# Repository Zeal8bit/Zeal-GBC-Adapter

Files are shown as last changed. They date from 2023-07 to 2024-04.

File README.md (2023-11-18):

## Gameboy (Color) cartridge adapter for Zeal 8-bit Computer

<center>
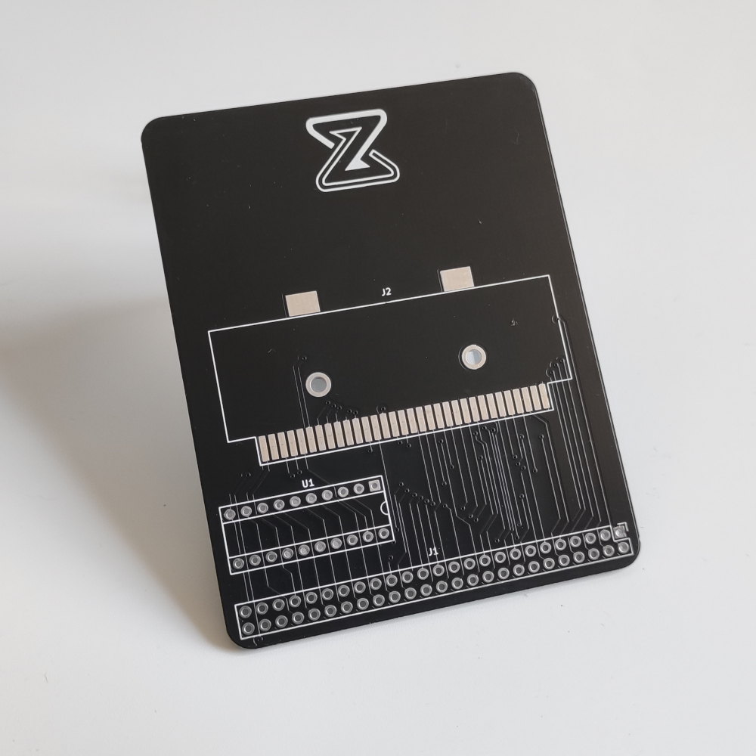
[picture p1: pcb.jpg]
PCB final result
    
</center>

### This repository is part of [this Youtube video](https://www.youtube.com/watch?v=MxnD7FFjDEM), check it for more information and explanation about this project.

The goal of this project is to create an adapter for connecting any Gameboy or Gameboy Color cartridge to Zeal 8-bit Computer. This will offer the possibility to backup the ROM or RAM (saved data), restore the saved data or even modify the saved data in place.

This repository includes:

* An example program, written in C, to communicate with the adapter. It will read RAM banks from the cartridge and send them through UART. This has been tested with MBC1 and MBC5 cartridges.
* A Python script to run on a host that will receive the data from UART and save them inside a file
* The source code to flash to the PLD (GAL16V8)
* A Kicad (v6) project for the schematics and PCB board

**DISCLAIMER: To prevent any data loss, NEVER plug or unplug the cartridges from the adapter when it is connected to a computer/board that is powered on! I am not responsible for any potential damage caused to the Gameboy cartridge when using the adapter. Use it at your own risk.**

### Requirements

To compile this example you will need:

* python3
  * pyserial package (`pip3 install pyserial`)
* bash
* git (to clone this repo)
* make
* Zeal 8-bit OS source code. Only the `kernel_headers` directory is required, check this repository.
z88dk v2.2 (or later). Only its assembler, z80asm, is strictly required. The latest version of z80asm must be used as earlier versions don't have support for `MACRO`.
To install z88dk, please check out their GitHub project.

### Build

To build the program, define the path to Zeal 8-bit OS, this will let us find the header files used to assemble the example:

```
export ZOS_PATH=/your/path/to/Zeal8bitOS
```

Then simply use the command:

```
cd software
make
```

After compiling, the folder `bin/` in `software/` should contain the binary `dump.bin`. This file can be then loaded to Zeal 8-bit OS through UART thanks to the `load` command.

The binary can also be embedded within the romdisk that will contain both the OS and a read-only file system. For example:

```
cd $ZOS_PATH
export EXTRA_ROMDISK_FILES="/path/to/this/repo/software/bin/dump.bin"
make
```

More info about compiling [Zeal 8-bit OS here](https://github.com/Zeal8bit/Zeal-8-bit-OS#getting-started).

The resulting ROM image can then be provided to an emulator or directly flashed to the computer's ROM that will use it.

### Usage

* On the Zeal 8-bit Computer, execute the dump program from the command line:

    ```
    A:/> ./dump.bin
    ```
    The program should detect the cartridge name, the RAM banks count and their size. The output should look like:
    ```
    POKEMON BLUE
    Cartridge type: 0x3
    Cartridge RAM size: 32 KB
    Ready to send, start the dump script on the host computer
    ```

* **Close the serial monitor on the host computer!** Else, the python script below will not be able to receive characters from the UART.

* On the host, execute the python script, you can use `-h` to have more info about the parameters. For example, to save the file as `PKM.sav` from UART node `/dev/ttyUSB0` with a baudrate of 57600, the following command can be used:

    ```
    python3 dump.py -o PKM.sav -d /dev/ttyUSB0 -b57600 -v
    ```

    The output should look like this:

    ```
    Connecting to /dev/ttyUSB0 with baudrate 57600
    Dumping 4 banks of 8192 bytes, 32768 bytes in total...
    PKM.sav successfully dumped
    ```

## Troubleshooting

Upon execution of the binary on the Zeal 8-bit computer, you may encounter the `Get attr error` issue. This shows that the serial driver in the Zeal 8-bit OS kernel doesn't support setting attributes (raw) via `ioctl`. In that case, you should update your installation of the Zeal 8-bit OS to get the latest version of the serial driver.

## License

Distributed under the Creative Commons Zero v1.0 Universal License. See LICENSE file for more information.

You are free to use it for personal and commercial use, the boilerplate present in each file must not be removed.

The `zeal8bit.com` silkscreen present on the PCB shall be kept.

## Contact

For any suggestion or request, you can contact me at contact [at] zeal8bit [dot] com or on the Discord server https://discord.gg/UzEjwRvBBb

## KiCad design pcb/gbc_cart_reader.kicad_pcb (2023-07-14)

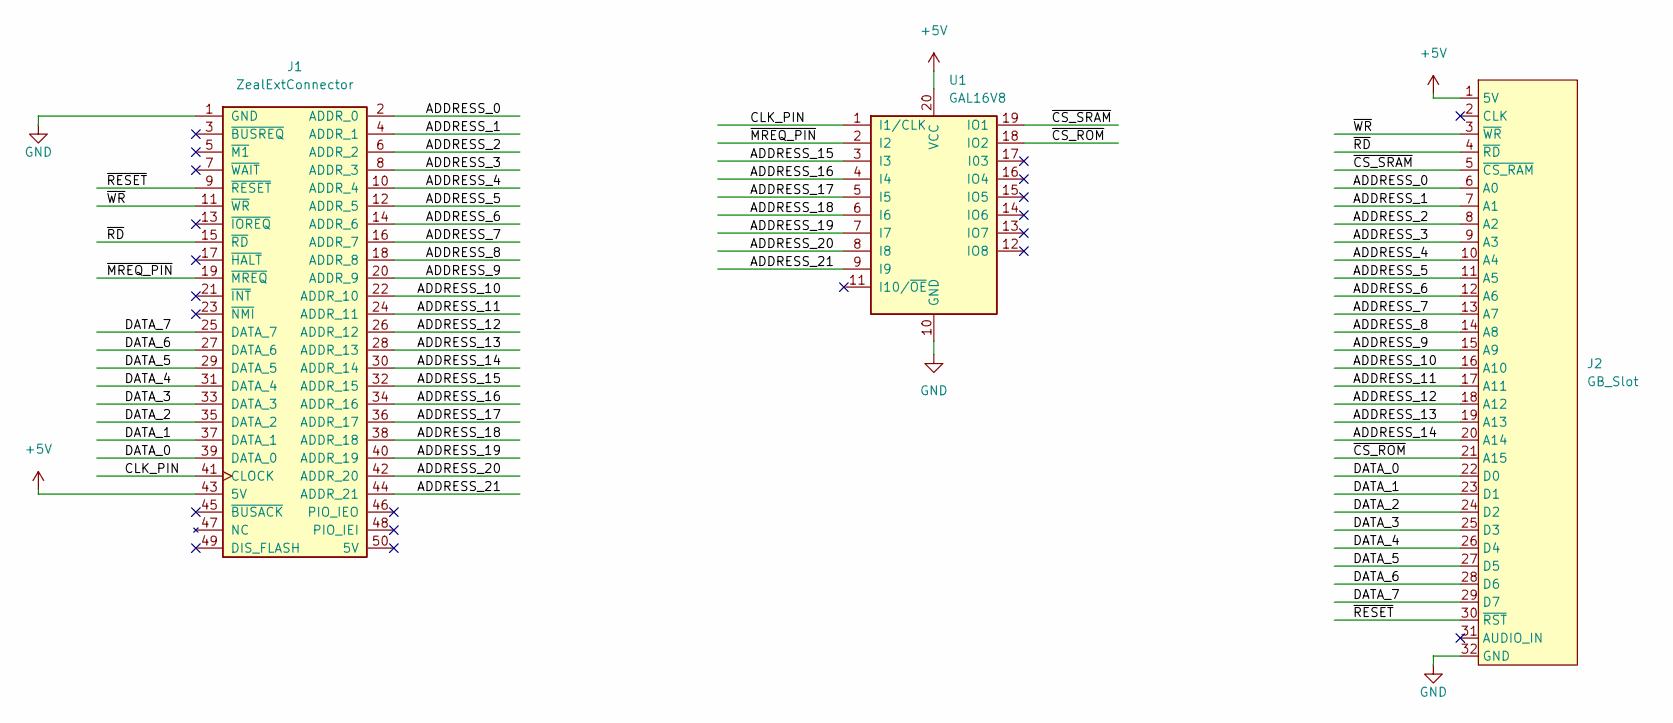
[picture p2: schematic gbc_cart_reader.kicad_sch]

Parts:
J1: ZealExtConnector; PinHeader_2x25_P2.54mm_Vertical
J2: GB_Slot; GB Slot
U1: GAL16V8; DIP-20_W7.62mm_Socket

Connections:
+5V: J1.43 (5V), J2.1 (5V), U1.20 (VCC)
/ADDRESS_0: J1.2 (ADDR_0), J2.6 (A0)
/ADDRESS_1: J1.4 (ADDR_1), J2.7 (A1)
/ADDRESS_2: J1.6 (ADDR_2), J2.8 (A2)
/ADDRESS_3: J1.8 (ADDR_3), J2.9 (A3)
/ADDRESS_4: J1.10 (ADDR_4), J2.10 (A4)
/ADDRESS_5: J1.12 (ADDR_5), J2.11 (A5)
/ADDRESS_6: J1.14 (ADDR_6), J2.12 (A6)
/ADDRESS_7: J1.16 (ADDR_7), J2.13 (A7)
/ADDRESS_8: J1.18 (ADDR_8), J2.14 (A8)
/ADDRESS_9: J1.20 (ADDR_9), J2.15 (A9)
/ADDRESS_10: J1.22 (ADDR_10), J2.16 (A10)
/ADDRESS_11: J1.24 (ADDR_11), J2.17 (A11)
/ADDRESS_12: J1.26 (ADDR_12), J2.18 (A12)
/ADDRESS_13: J1.28 (ADDR_13), J2.19 (A13)
/ADDRESS_14: J1.30 (ADDR_14), J2.20 (A14)
/ADDRESS_15: J1.32 (ADDR_15), U1.3 (I3)
/ADDRESS_16: J1.34 (ADDR_16), U1.4 (I4)
/ADDRESS_17: J1.36 (ADDR_17), U1.5 (I5)
/ADDRESS_18: J1.38 (ADDR_18), U1.6 (I6)
/ADDRESS_19: J1.40 (ADDR_19), U1.7 (I7)
/ADDRESS_20: J1.42 (ADDR_20), U1.8 (I8)
/ADDRESS_21: J1.44 (ADDR_21), U1.9 (I9)
/CLK_PIN: J1.41 (CLOCK), U1.1 (I1/CLK)
/DATA_0: J1.39 (DATA_0), J2.22 (D0)
/DATA_1: J1.37 (DATA_1), J2.23 (D1)
/DATA_2: J1.35 (DATA_2), J2.24 (D2)
/DATA_3: J1.33 (DATA_3), J2.25 (D3)
/DATA_4: J1.31 (DATA_4), J2.26 (D4)
/DATA_5: J1.29 (DATA_5), J2.27 (D5)
/DATA_6: J1.27 (DATA_6), J2.28 (D6)
/DATA_7: J1.25 (DATA_7), J2.29 (D7)
/~CS_ROM: J2.21 (A15), U1.18 (IO2)
/~CS_SRAM: J2.5 (~CS_RAM), U1.19 (IO1)
/~MREQ_PIN: J1.19 (~MREQ), U1.2 (I2)
/~RD: J1.15 (~RD), J2.4 (~RD)
/~RESET: J1.9 (~RESET), J2.30 (~RST)
/~WR: J1.11 (~WR), J2.3 (~WR)
GND: J1.1 (GND), J2.32 (GND), U1.10 (GND)

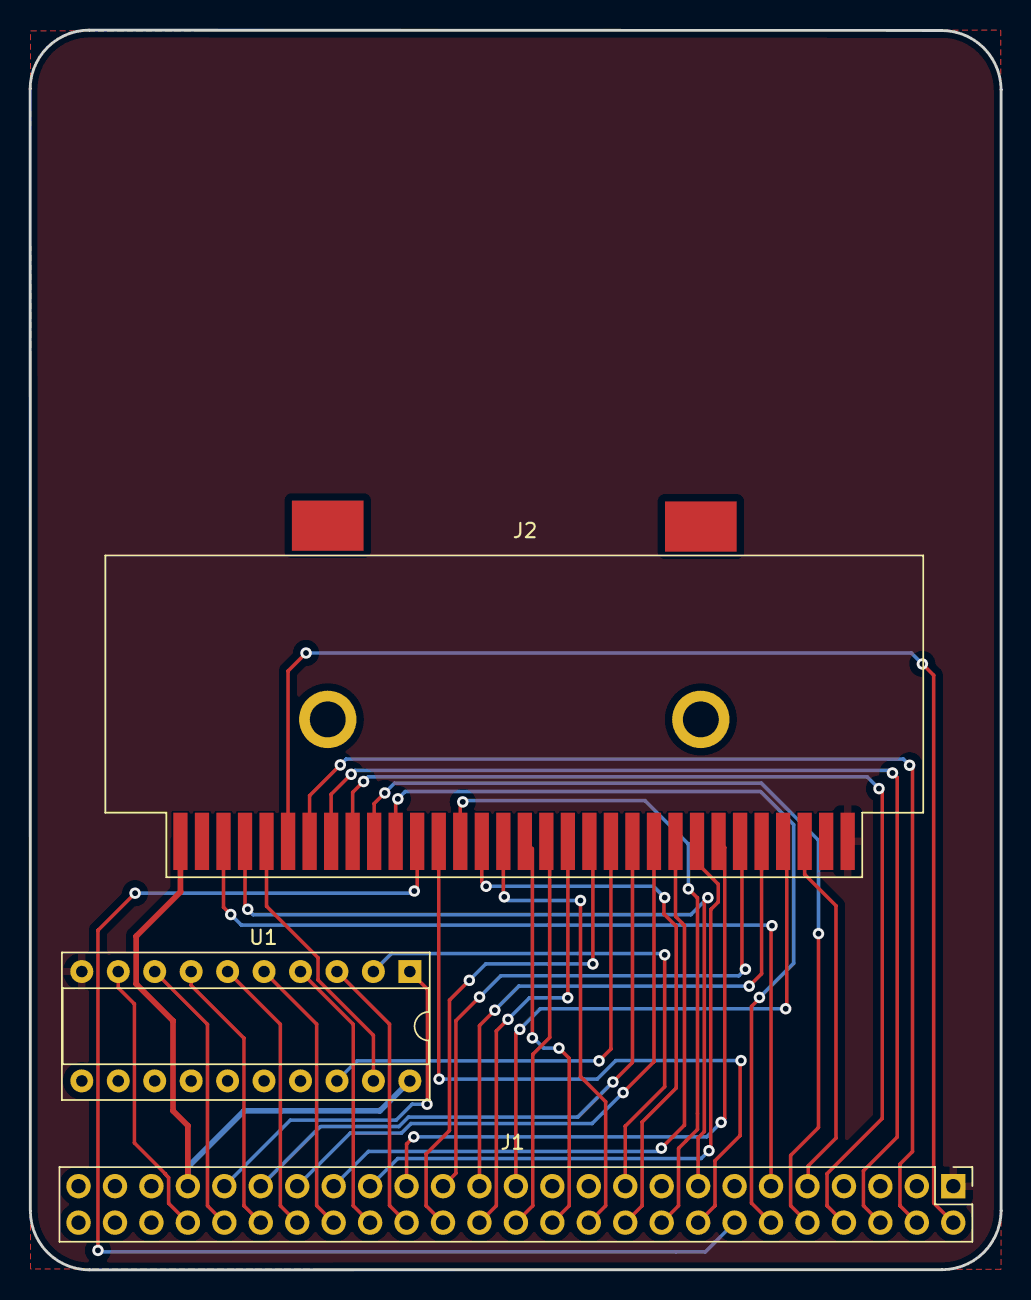
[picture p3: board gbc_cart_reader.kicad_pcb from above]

Board: 2 copper layers, 67.7 x 86.4 mm, 3 parts (0 on the bottom side), 39 nets.

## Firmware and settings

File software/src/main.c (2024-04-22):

/* SPDX-FileCopyrightText: 2023 Zeal 8-bit Computer <contact@zeal8bit.com>
 *
 * SPDX-License-Identifier: CC0-1.0
 */

#include <stdio.h>
#include <stdint.h>
#include <stdlib.h>
#include "zos_errors.h"
#include "zos_vfs.h"
#include "zos_sys.h"
#include "zos_serial.h"

/* If the standard output is the same serial driver as the one used to backup the cartridge,
 * we shall not output anything during the dump. After backing up, wait for a character before exiting. */
#define STDOUT_IS_SERIAL    1

/* Define different cartridges type */
#define MBC1_RAM_BATT       0x3
#define MBC2_RAM_BATT       0x6
#define ROM_RAM_BATT        0x10
#define MBC3_RAM_BATT       0x13
#define MBC5_RAM_BATT       0x1b
#define MBC5_RUMB_RAM_BATT  0x1e

/* Gameboy cartridge will be mapped at physical address 0x3f0000  */
#define GB_PHYS_ADDR            (0x3f0000)

/**
 * The first page is the kernel, we can't touch it, the second page is the current program,
 * the third page is available and the forth page is the stack for this current program.
 * Use the third page to map the GB cartridge data
 */
#define GB_CART_VIRT_ADDR       (0x8000)

/**
 * Each SRAM bank in the cartridge is 8KB big
 */
#define GB_SRAM_BANK_SIZE       (8*1024)

/**
 * Pointer to the cartridge virtual address
 */
uint8_t* cart_virt = (uint8_t*) GB_CART_VIRT_ADDR;

/**
 * Opened dev for the UART, needs to be closed before exiting!
 */
zos_dev_t uart_dev = 0;

/**
 * Attributes of the opened UART
 */
uint16_t uart_attr = 0;

/**
 * @brief Helper function to map cartridge given address into virtual page 3
 *
 * @param cart_addr Relative address of the cartridge to map, MUST BE A MULTIPLE OF 16KB!
 */
static void map_cart_phys(uint16_t cart_addr)
{
    zos_err_t err = map((void*) GB_CART_VIRT_ADDR, GB_PHYS_ADDR + cart_addr);
    if (err != ERR_SUCCESS) {
        printf("Error cartridge map\n");
        if (uart_dev) {
            close(uart_dev);
        }
        exit(0);
    }
}

/**
 * @brief Map the given cartridge SRAM bank into virtual page 3
 */
static void map_cart_sram(uint8_t bank)
{
    /* To switch the bank, write to cartridge address 0x4000 */
    map_cart_phys(0x4000);
    /* Only keep the lower 4 bits */
    cart_virt[0] = bank & 0xF;
    /* SRAM bank was mapped in the cartridge itself! Map the SRAM into the virtual page */
    map_cart_phys(0x8000);
}


/**
 * @brief Size of the cartridge RAM size, in KB
 *
 * @param size_value Size byte located in the cartridge ROM, at offset 0x149
 */
uint8_t cartridge_RAM_size(uint8_t size_value)
{
    uint8_t size = 0;
    switch (size_value) {
        case 2:
            size = 8;
            break;
        case 3:
            size = 32;
            break;
        case 4:
            size = 128;
            break;
        case 5:
            size = 64;
            break;
        default:
            size = 0;
            break;
    }
    return size;
}

static void wait_for_host(uint8_t bank_num, uint16_t bank_size)
{
    zos_err_t err;
    uint16_t size = 0;
    char msg[4] = { 0 };

    printf("Ready to send, start the dump script on the host computer\n");
    while (1) {
        /* Wait for a message from the host */
        size = 1;
        err = read(uart_dev, msg, &size);

        /* Make sure it is '!' */
        if (err != ERR_SUCCESS || msg[0] != '!') {
            printf("Invalid message from the host, please retry\n");
            continue;
        }

        /* Send the number of banks and the bank size */
        msg[0] = '=';
        msg[1] = bank_num;
        msg[2] = bank_size & 0xff;
        msg[3] = bank_size >> 8;
        size = 4;
        write(uart_dev, msg, &size);
        break;
    }
}

int main (void)
{
    zos_err_t err;

    /* Open the serial driver to send the data to */
    uart_dev = open("#SER0", O_WRONLY);
    if (uart_dev < 0) {
        printf("Error opening serial driver\n");
        exit(0);
    }

    /* Start by mapping the fixed part of the ROM. It contains info about the cartridge itself.
     * (size, MBC, ram size, etc...) */
    map_cart_phys(0);

    /* Offset 0x134 of the cartridge should contain the name of the game, only print 15 characters */
    const char* name = cart_virt + 0x134;
    uint16_t size = 15;
    write(DEV_STDOUT, name, &size);

    /* Determine the size and number of the RAM banks thanks to the cartridge type, located at offset
     * 0x147 of the ROM. */
    uint8_t bank_num = 0;
    uint16_t bank_size = GB_SRAM_BANK_SIZE;
    const uint8_t cart_type = cart_virt[0x147];

    /* Previous "write" didn't output a newline, output it here before the string */
    printf("\nCartridge type: 0x%hx\n", cart_type);
    switch (cart_type) {
        case MBC1_RAM_BATT:
        case ROM_RAM_BATT:
        case MBC3_RAM_BATT:
        case MBC5_RAM_BATT:
        case MBC5_RUMB_RAM_BATT:
            /* Cartridge RAM size pointer, located at offset 0x149 of the ROM. */
            size = cartridge_RAM_size(cart_virt[0x149]);
            bank_num = size >> 3;
            printf("Cartridge RAM size: %d KB\n", size);
            break;
        case MBC2_RAM_BATT:
            bank_size = 512;
            bank_num = 1;
            printf("Cartridge RAM size: %d B\n", bank_size);
            break;
        default:
            printf("Unsupported cart type, exiting...\n");
            goto err_close_exit;
    }

    /* Set the serial driver to RAW (to avoid \n to \r\n conversion) */
    err = ioctl(uart_dev, SERIAL_CMD_GET_ATTR, (void*) &uart_attr);
    if (err != ERR_SUCCESS) {
        printf("Get attr error %d\n", err);
        goto err_close_exit;
    }

    wait_for_host(bank_num, bank_size);

    if ((uart_attr & SERIAL_ATTR_MODE_RAW) == 0) {
        err = ioctl(uart_dev, SERIAL_CMD_SET_ATTR, (void*) (uart_attr | SERIAL_ATTR_MODE_RAW));
        if (err != ERR_SUCCESS) {
            printf("Set attr error %d\n", err);
            goto err_close_exit;
        }
    }

    /* Enable the RAM: the first 8KB of the cartridge can be used to enable the cartridge RAM by writing 0xA to it */
    cart_virt[0] = 0xA;

    /* Enable RAM banking from "Banking Mode Select" register.
     * This register can be written to when writing cartridge's address 6000–7FFF. Let's map this area to the virtual page.
     *
     * NOTE: We can only map physical pages multiple of 16KB! The solution is to map 0x4000 and write at address 0x2000.
     */
    if (cart_type == MBC1_RAM_BATT) {
        /* MBC1 Only */
        map_cart_phys(0x4000);
        /* We need to write 1 to it to enable RAM banking (0 disables banking) */
        cart_virt[0x2000] = 1;
    }

    /* Finally, let's use our own function to map the cartridge RAM. Let's hardcode the number of banks for the moment */
    for (uint8_t bank = 0; bank < bank_num; bank++) {
        /* In the case where #SER0 is the same driver as the STDOUT, we shall not write anything to STDOUT while backup is on-going */
#if !STDOUT_IS_SERIAL
        printf("Backing up bank %d...\n", bank);
#endif
        map_cart_sram(bank);
        /* The SRAM 8KB bank is now mapped at GB_CART_VIRT_ADDR still, so we can access it with `cart_virt` array,
         * send the content to the UART. */
        size = bank_size;
        err = write(uart_dev, cart_virt, &size);
        if (err != ERR_SUCCESS) {
            printf("Error %d, exiting\n", err);
            goto err_set_attr;
        }
    }

err_set_attr:
    /* Restore UART attributes before exiting */
    if ((uart_attr & SERIAL_ATTR_MODE_RAW) == 0) {
        ioctl(uart_dev, SERIAL_CMD_SET_ATTR, (void*) uart_attr);
    }

err_close_exit:
    /* Finished using the UART, close it */
    close(uart_dev);

    /* Disable the cartridge RAM */
    map_cart_phys(0);
    cart_virt[0] = 0;

    return 0;
}

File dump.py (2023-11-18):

import argparse
import serial

DEFAULT_BAUDRATE = 57600

# Define the parameters for the program
parser = argparse.ArgumentParser(
                prog='dump.py',
                description='Read and dump cartridge saves from Zeal 8-bit Computer to a file'
            )
parser.add_argument('-o', dest='outfile', help='Output save file name', required=True)
parser.add_argument('-d', dest='ttynode', help='UART device node, e.g. /dev/ttyUSB0', required=True)
parser.add_argument('-v', '--verbose', dest='verbose', help='Enable verbose mode', required=False, action='store_true')
parser.add_argument('-b', dest='baudrate', type=int, help='Baudrate to use with the serial node', default=DEFAULT_BAUDRATE, required=False)
args = parser.parse_args()

if args.verbose:
    print("Connecting to " + args.ttynode + " with baudrate " + str(args.baudrate))


# Let's have a timeout of around one second
ser = serial.Serial(args.ttynode, args.baudrate, timeout=args.baudrate)

# Create the destination file
outfile = open(args.outfile, "wb")

# We are ready, send '!' to the 8-bit computer
ser.write(b'!')

# Wait for the message containing:
# '=' character
# Number of banks to dump, in binary (8-bit)
# Size of each bank, in binary (16-bit little-endian)
bytes = ser.read(4)

if bytes[0] != ord('='):
    print("Invalid message header from the 8-bit computer: ", hex(bytes[0]))
    exit(1)

bank_num  = bytes[1]
bank_size = (bytes[2]) | (bytes[3] << 8)
total = bank_num * bank_size

print("Dumping %d banks of %d bytes, %d bytes in total..." % (bank_num, bank_size, total))

# Receive all the data from the other end
bytes = ser.read(total)

# Store the bytes in the file
outfile.write(bytes)

# Success, end the program
print(args.outfile + " successfully dumped")
outfile.close()

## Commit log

2023-07-14 Add the PCB, the PLD program and the example software to backup MBC1 and MBC5 Gaemboy games.
    [gbc_cart_reader.kicad_pcb, gbc_cart_reader.kicad_sch]
2023-11-18 Added support to Zeal 8-bit OS implementation using UART as standard output
    This commit brings in a new (Python) script that will ease dump of the cartridge
    save file to the host computer, please check the README.
